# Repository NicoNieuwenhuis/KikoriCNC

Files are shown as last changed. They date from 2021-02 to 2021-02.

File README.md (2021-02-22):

# #KikoriCNC #CNC #Open Source Hardware #Hardware Hackers #Made in the Neighborhood

# Kikori CNC Open Source Program
The kikori is an open source entry-level machine for small businesses.
Read ReadMe.txt for instructions on how to build.

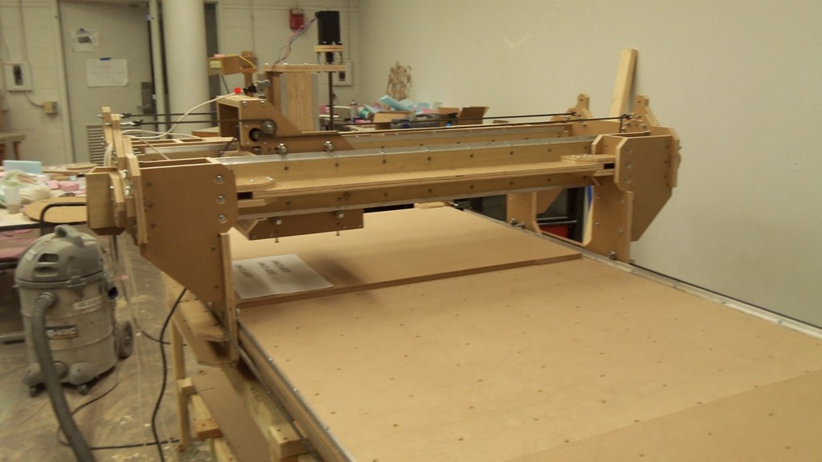
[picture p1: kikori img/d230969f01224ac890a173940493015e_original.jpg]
Kikori CNC


As Found on http://www.sindrianarts.com
You van visit the original site on https://web.archive.org/web/20150306220402/http://www.sindrianarts.com/

Can be used with:
http://linuxcnc.org/

Images:

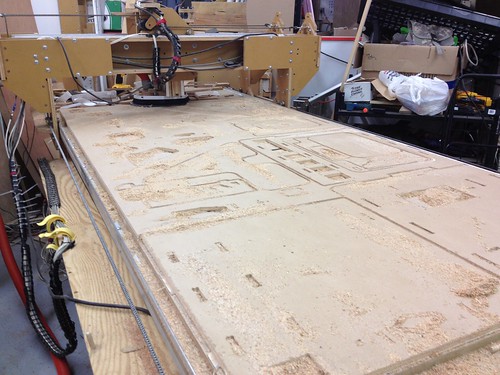
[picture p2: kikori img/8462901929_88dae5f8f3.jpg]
Kikori CNC1


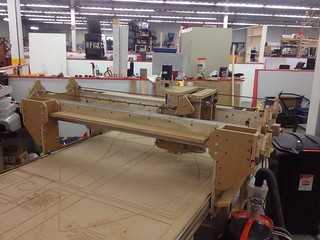
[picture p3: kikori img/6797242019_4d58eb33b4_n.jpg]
Kikori CNC2


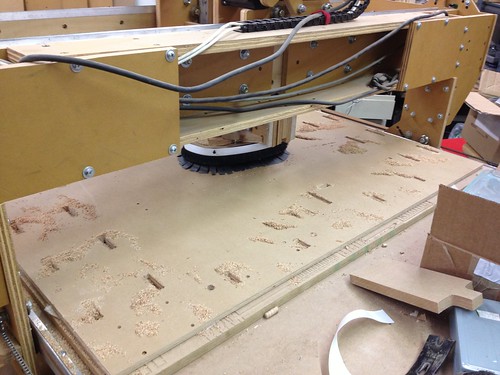
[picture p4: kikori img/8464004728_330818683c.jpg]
Kikori CNC3


License:

THE WORK (AS DEFINED BELOW) IS PROVIDED UNDER THE TERMS OF THIS CREATIVE COMMONS PUBLIC LICENSE ("CCPL" OR "LICENSE"). THE WORK IS PROTECTED BY COPYRIGHT AND/OR OTHER APPLICABLE LAW. ANY USE OF THE WORK OTHER THAN AS AUTHORIZED UNDER THIS LICENSE OR COPYRIGHT LAW IS PROHIBITED.

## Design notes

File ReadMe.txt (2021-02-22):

These files comprise the part layouts for the Kikori 1.4 Open Source CNC Gantry Router.

'Kikori sheet 1' should be milled out of two 48" x 48" sheets of 3/4" MDO stacked on top of eachother.
All other layers should be milled to a depth of 1.6" to ensure that the cuts go all the way through both sheets.

'Kikori sheet 1 mirror insets' should be used to mill insets on the second of the large "L" shaped pieces that was on the bottom sheet of two milled using 'Kikori sheet 1'.  You should end up with two pieces with insets that are the mirror image of each other.

'Kikori sheet 2' should be milled out of one 48" x 48" sheet of 3/4" MDO.

Notes on DXF layers:
All layer names indicate what type of operation that layer requires:
Layers called 'profiles' should be milled on the outside of the line all the way through the material.
Layers called 'skin profiles should be milled to a depth of 0.7", leaving a 0.05" thick "skin" to be cut away manually with a knife.
Layers called 'slots' or 'slots + holes' should be milled on the inside of the line all the way through the material.
Layers called 'drill X"' should be drilled with the indicated drill diameter.
Layers containing the word 'pocket' should be pocketed to the indicated depth.
Layers containing the word 'inset' should be milled on the inside of the line to the indicated depth.

For support, please visit http://www.sindrianarts.com

This work is licensed under the Creative Commons Attribution-NonCommercial-ShareAlike 3.0 Unported License. To view a copy of this license, visit http://creativecommons.org/licenses/by-nc-sa/3.0/ or send a letter to Creative Commons, 444 Castro Street, Suite 900, Mountain View, California, 94041, USA.

Version Log

1.4	First release
1.4.2	Minor file format issues fixed
1.4.3	Vacuum mount size fixed, DXF versions changed to R2000-2002 ASCII

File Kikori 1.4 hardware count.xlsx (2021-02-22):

 | cross dowel | 1/4" nut | 1/4" washer | 1/4 x 1.5 screw | 1/4" x 1.75" screw | 1/4 x 2.5 screw | 1.4 x 3" screw | 1.25" #8, nuts, washers | 1/4" 1.5" eye bolts | 1/4" 3" eye bolts | 1/4"x3.75z" screw | 3/8 x 1.5" screw | 3/8" x 2" screws | 3/8" x 3" screws | 3/8" washer | 3/8" nut | v bearing, small 3/8 washer | 1/4" ID bearing | 1/2" ID bearing | drive sprocket | idle sprocket | #25 rollerchain (in) | 1/2" 14" long lead screw, nut
for? |  |  |  | cd + rail | cd + 1 layer | cd + 2 layer, cd bearing adjust | 3 layer +nut |  |  |  | z rails, router mount, z motor mount |  | Y v bearings | v bearing + idle sprocket, 3 layer + nut
Total | 225 | 81 | 305 | 44 | 160 | 46 | 20 | 8 | 2 | 2 | 17 | 6 | 18 | 4 | 52 | 30 | 24 | 5 | 0 | 2 | 6 | 0 | 1
Z gantry | 15 | 29 | 37 | 0 | 8 | 0 | 0 | 4 | 0 |  | 17 | 0 | 0 |  | 0 |  | 0 | 0 |  | 0 | 0 | 0 | 1
rails |  | 10 |  |  |  |  |  |  |  |  | 10
bottom half | 8 | 3 | 14 |  | 8 |  |  |  |  |  | 3
top half | 7 | 16 | 23 |  |  |  |  | 4 |  |  | 4 |  |  |  |  |  |  |  | 1 |  |  |  | 1
Y gantry | 34 | 0 | 24 | 0 | 24 | 10 | 4 | 4 | 0 | 0 | 0 | 0 | 16 | 2 | 32 | 16 | 16 | 3 | 0 | 2 | 2 | 0 | 0
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

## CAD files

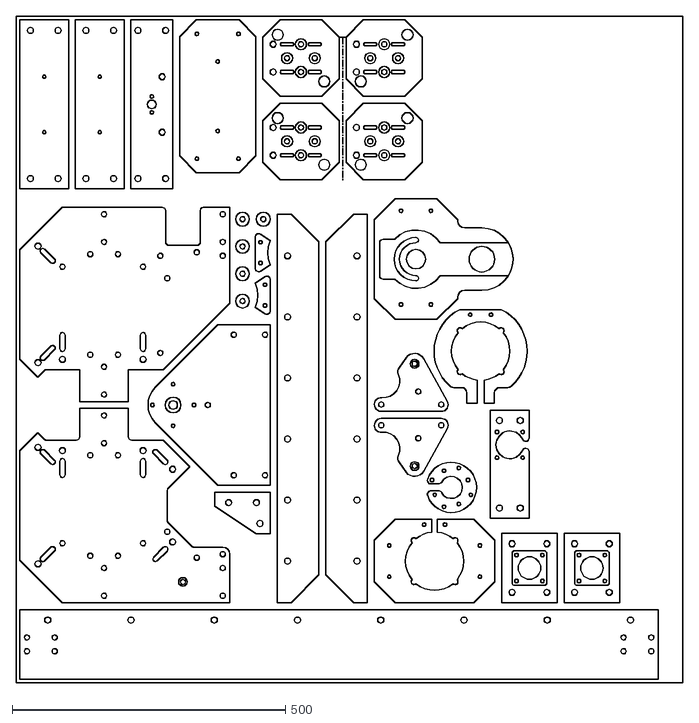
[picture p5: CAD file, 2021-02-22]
Kikori sheet 2.dxf
1219.2 x 1219.2

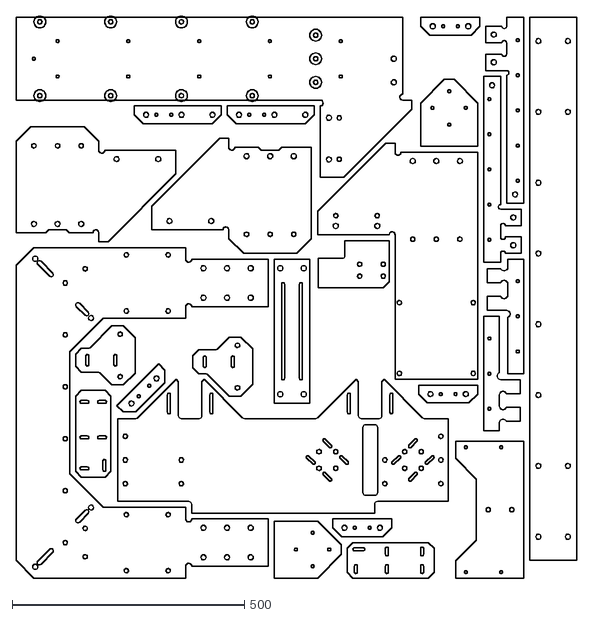
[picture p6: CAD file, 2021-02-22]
Kikori sheet 1.dxf
1206.5 x 1209.7
